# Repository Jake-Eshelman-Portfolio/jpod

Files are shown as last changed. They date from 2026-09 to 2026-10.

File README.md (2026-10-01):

# jPod Project Summary

## Goal
A handheld, music-only player about the size of an iPod Video. Stores 32–64GB of music, has a small screen with menus, a 4-way D-pad plus select, Bluetooth headphones, and a wired 3.5mm jack as backup.

## Core design
- **Brain:** ESP32-WROVER (original ESP32). It has classic Bluetooth for headphone audio, Wi-Fi, and 8MB of extra RAM for buffering.
- **Audio:** TI TLV320DAC3100 DAC with a built-in headphone amp, feeding a 3.5mm jack.
- **Storage:** microSD card.
- **Screen:** 2" ST7789 color display.
- **Power:** LiPo battery (1500–2500mAh), USB-C charging, battery-level chip.
- **Software:** Rust on ESP-IDF (`std`). Symphonia handles MP3/FLAC decoding and tags.

## Features
- **Local playback** from the SD card, browsing by artist and album.
- **Streaming** from Navidrome on the Pi over Wi-Fi. Away from home, it reaches the Pi through Tailscale Funnel, protected by a password and a secret token.
- **"Find similar":** pick a song, and the Pi asks Last.fm for similar tracks, then plays any matches from the library or adds the rest to a wishlist.
- **Firmware updates** over Wi-Fi.

## Decisions
- Start with one ESP32. Add a second one for Bluetooth only if streaming over Wi-Fi while playing through Bluetooth stutters.
- Use a 3.5mm jack instead of USB-C headphones.
- Leave LTE for v2, but reserve a spare UART and power header on v1.
- Skip Spotify's API, since it's too locked down now. Use Last.fm instead.

## Plan
1. **Prototype on a breadboard** with a dev kit and breakouts, powered over USB.
2. **Write the software:** playback, UI, Bluetooth, streaming, "find similar".
3. **Design the custom PCB in KiCad** using the same chips.
4. **Order parts.** Separate BOM for schematic based final build and the prototype that will be used to create a test bench.

## Prepare an SD Card (Linux/WSL)
1. Insert the card and inspect disks and partitions:
	```bash
	lsblk -o NAME,PATH,TRAN,RM,SIZE,MODEL,TYPE,FSTYPE,MOUNTPOINTS
	```
2. Identify the removable USB **disk** by model and capacity. Use the whole-disk path (for example, `/dev/sde`), not a partition path such as `/dev/sde1`. The script erases the whole selected disk and creates one MBR/FAT32 partition; Linux sees the USB reader and cannot prove what media is inserted.
3. Ensure `mp3_samples/` contains at least one MP3, then run from the repository root, substituting the verified disk path:
	```bash
	sudo ./helper_scripts/partition_sd_card.sh /dev/sde
	```
4. Check the script's printed model, capacity, and partition list carefully. Continue only if they match the SD card you intend to erase, then type the exact confirmation it requests (device path and size in bytes).

5. To check the music on card:
    - sudo mkdir -p /mnt/jpod-card
    - sudo mount /dev/sde1 /mnt/jpod-card
    - ls /mnt/jpod-card/mp3_samples
    - sudo umount /mnt/jpod-card

The script refuses mounted or otherwise in-use disks. Install its Linux tools if needed with `sudo apt install util-linux fdisk parted dosfstools udev coreutils findutils gawk` (`parted` provides `partprobe`).

## Watch out for
- Wi-Fi and Bluetooth share one radio on the ESP32, so buffer streams aggressively.
- The DAC needs its own 1.8V supply on the custom board.
- The CP2102N USB chip has a long lead time, so buy it early or find a good substitution.

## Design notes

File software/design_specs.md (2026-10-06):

# Software Design

## Main and Workers

- `main` initializes the hardware and starts the workers.
- Each worker owns its device state and runs on its own thread.
- Screen and SD workers are active objects, have mailbox and address that serves as interface

## Shared SPI Bus

- `main` owns one SPI bus driver.
- Screen and SD workers borrow the bus and create separate device handles with separate chip-select pins.
- ESP-IDF serializes transfers from these device handles on the shared bus.
- Lifetimes keep the device wrappers from outliving the bus

## Button Interrupts

- A normal thread runs `register_button_interrupts` and owns the button pins.
- A full screen mailbox drops that event. 
- A disconnected mailbox ends the button worker since program currently will restart if an active object fails

## Runtime and Failures

- Workers are intended to run for the whole powered session.
- Screen and SD threads use a scope because they borrow the SPI bus.
- The button thread uses normal `spawn` because it owns its inputs and does not borrow the bus.
- A worker exit or handled startup failure logs a short reason and restarts the chip.
- We do not join running workers for shutdown since we plan to full restart anyways
- TODO: Log detailed worker errors before restarting.

## Power and Sleep

- Add explicit worker shutdown later only if we need task restarts or tests that must end cleanly.

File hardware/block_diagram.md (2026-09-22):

```mermaid
flowchart TB
    USB["USB-C"] --> UART["USB-UART<br/>CP2102N"]
    USB --> PWR["Power<br/>Charger + 3.3V Regulator"]
    BATT["LiPo Battery"] --- PWR
    PWR -->|3.3V| MCU

    UART -->|UART| MCU
    MCU["ESP32-WROVER-E"]

    MCU -->|I2S / I2C| DAC["Audio DAC<br/>TLV320DAC3100"] --> JACK["3.5mm Jack"]
    MCU -->|SPI via 22-pin FFC| DISP["Display<br/>ER-TFT020-7"]
    MCU -->|SPI| SD["microSD"]
    BTN["Buttons / D-pad"] -->|GPIO| MCU
```

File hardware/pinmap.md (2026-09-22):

# ESP32-WROVER-E-N16R8 — Pin Map / Plan

DIY music player (JPod). Module: **ESP32-WROVER-E-N16R8** (16 MB flash, 8 MB PSRAM).

> **WROVER note:** GPIO6–11 are used internally for SPI flash and GPIO16/17 for PSRAM — none are broken out on this module, so they don't appear here. Don't plan to use them.

---

## 1. Peripheral assignment (the plan)

| Function | Signal | GPIO | Notes |
| --- | --- | --- | --- |
| **I²C** (DAC ctrl + fuel gauge) | SDA | IO21 | 4.7k pull-up to 3V3 |
| | SCL | IO22 | 4.7k pull-up to 3V3 |
| **I²S** (audio → TLV320DAC3100) | BCLK | IO26 | |
| | WS / LRCLK | IO25 | |
| | DOUT (data to DAC) | IO14 | |
| | MCLK | *(optional)* GPIO0 | DAC can run off BCLK via internal PLL; only wire MCLK if needed — GPIO0 is shared with boot/auto-reset, so avoid if you can |
| **SPI bus** (ER-TFT020-7 display + SD, shared) | SCK | IO18 | |
| | MOSI | IO23 | |
| | MISO | IO19 | SD only (ST7789 is write-only) |
| **Display (ER-TFT020-7)** | CS | IO5 | strapping — safe as an output |
| | DC | IO27 | |
| | RST | *(tie to EN)* | share the ESP32 reset to save a pin, or use a free GPIO |
| | BL (backlight) | IO4 | PWM dimming |
| **microSD (DM3AT)** | CS | IO13 | |
| **Buttons — D-pad** | Up | IO34 | input-only → **needs external 10k pull-up** |
| | Down | IO35 | input-only → **external 10k pull-up** |
| | Left | IO36 (SENSOR_VP) | input-only → **external 10k pull-up** |
| | Right | IO39 (SENSOR_VN) | input-only → **external 10k pull-up** |
| **Button — Select** | SEL | IO32 | internal pull-up OK |
| **HP jack detect** | DET | IO33 | optional; confirm detect contact on SJ-43514 |
| **Fuel gauge ALRT** | ALRT | *(optional)* IO15 | idles high (OK at boot); or leave NC and poll over I²C |
| **Charger status** | CHG / PGOOD | *(optional)* NC | BQ24075 open-drain status; wire only if pins free |

**Reserved — do not reassign:**

| Signal | GPIO / Pin | Why |
| --- | --- | --- |
| EN | pin 3 | reset/enable — pull-up + RC cap |
| IO0 | pin 25 | boot strap + auto-reset circuit |
| TXD0 | GPIO1 (pin 35) | UART0 — programming/serial console |
| RXD0 | GPIO3 (pin 34) | UART0 — programming/serial console |

---

## 2. Full pin reference (all 47)

| Pin | Label | GPIO | Class | Plan |
| --- | --- | --- | --- | --- |
| 1 | GND_2 | — | power | GND |
| 2 | 3V3 | — | power | 3.3V rail |
| 3 | EN | — | reset | pull-up + RC; opt. LCD_RST here |
| 4 | SENSOR_VP | IO36 | **input-only** | Btn Left (ext pull-up) |
| 5 | SENSOR_VN | IO39 | **input-only** | Btn Right (ext pull-up) |
| 6 | IO34 | IO34 | **input-only** | Btn Up (ext pull-up) |
| 7 | IO35 | IO35 | **input-only** | Btn Down (ext pull-up) |
| 8 | IO32 | IO32 | full GPIO | Btn Select |
| 9 | IO33 | IO33 | full GPIO | HP jack detect |
| 10 | IO25 | IO25 | full GPIO (DAC) | I²S WS |
| 11 | IO26 | IO26 | full GPIO (DAC) | I²S BCLK |
| 12 | IO27 | IO27 | full GPIO | LCD DC |
| 13 | IO14 | IO14 | full GPIO | I²S DOUT |
| 14 | IO12 | IO12 | **strap (boot LOW)** | free — keep low/floating at boot |
| 15 | GND_3 | — | power | GND |
| 16 | IO13 | IO13 | full GPIO | SD CS |
| 17–22 | NC_2–7 | — | n/c | leave open |
| 23 | IO15 | IO15 | **strap (idles high)** | opt. fuel-gauge ALRT |
| 24 | IO2 | IO2 | **strap (boot LOW/float)** | free — use carefully |
| 25 | IO0 | IO0 | **strap / boot** | boot + auto-reset (reserved) |
| 26 | IO4 | IO4 | full GPIO | LCD backlight (PWM) |
| 27 | NC_8 | — | n/c | leave open |
| 28 | NC_9 | — | n/c | leave open |
| 29 | IO5 | IO5 | strap (safe as output) | LCD CS |
| 30 | IO18 | IO18 | full GPIO | SPI SCK |
| 31 | IO19 | IO19 | full GPIO | SPI MISO |
| 32 | NC | — | n/c | leave open |
| 33 | IO21 | IO21 | full GPIO | I²C SDA |
| 34 | RXD0 | IO3 | UART0 | serial console (reserved) |
| 35 | TXD0 | IO1 | UART0 | serial console (reserved) |
| 36 | IO22 | IO22 | full GPIO | I²C SCL |
| 37 | IO23 | IO23 | full GPIO | SPI MOSI |
| 38 | GND | — | power | GND |
| 39–47 | EPAD / EPAD_2–9 | — | thermal pad | all to GND |

---

## 3. Constraints cheat-sheet

- **Input-only (no output, no internal pull-up):** GPIO34, 35, 36, 39 → used for the 4 D-pad buttons, each with an **external 10k pull-up** to 3V3, button to GND.
- **Strapping pins** (level at power-up sets boot behavior): IO0, IO2, IO5, IO12, IO15.
  - IO12 must be **LOW at boot** (sets flash voltage) — don't hang a pulled-high signal on it.
  - IO0 → boot/download select, owned by auto-reset circuit.
  - IO5 / IO15 default high — fine as outputs / high-idle inputs.
- **UART0 (IO1/IO3):** keep for CP2102N programming + console.
- Add **test pads / header** for TXD0, RXD0, EN, IO0, GND — manual-flash fallback if the auto-reset circuit has a bug on rev A.

---

## 4. Firmware defines (Arduino / ESP-IDF)

```c
// ---- I2C ----
#define PIN_I2C_SDA    21
#define PIN_I2C_SCL    22

// ---- I2S (audio to TLV320DAC3100) ----
#define PIN_I2S_BCLK   26
#define PIN_I2S_WS     25
#define PIN_I2S_DOUT   14
// #define PIN_I2S_MCLK 0   // only if DAC PLL not used

// ---- SPI (display + SD) ----
#define PIN_SPI_SCK    18
#define PIN_SPI_MOSI   23
#define PIN_SPI_MISO   19
#define PIN_LCD_CS     5
#define PIN_LCD_DC     27
#define PIN_LCD_BL     4
// LCD_RST tied to EN
#define PIN_SD_CS      13

// ---- Buttons ----
#define PIN_BTN_UP     34   // input-only, ext pull-up
#define PIN_BTN_DOWN   35   // input-only, ext pull-up
#define PIN_BTN_LEFT   36   // input-only, ext pull-up
#define PIN_BTN_RIGHT  39   // input-only, ext pull-up
#define PIN_BTN_SEL    32   // internal pull-up

// ---- Misc ----
#define PIN_HP_DETECT  33
// #define PIN_FUELGAUGE_ALRT 15  // optional
```

---

## 5. Open items

- [ ] Confirm SJ-43514 detect-pin behavior (which contact, active level).
- [ ] Decide MCLK: rely on DAC internal PLL (preferred) vs wire GPIO0.
- [ ] Verify the ER-TFT020-7 FFC pinout, power rails, and backlight connection before finalizing the display net labels.
- [ ] Confirm FH12-22S-0.5SH(55) footprint, FFC contact orientation, and cable length.
- [ ] Decide LCD_RST: tie to EN vs dedicate a GPIO.
- [ ] Wire BQ24075 CHG/PGOOD status to GPIO? (optional UI nicety)
- [ ] Add external 10k pull-ups for the 4 input-only D-pad buttons.

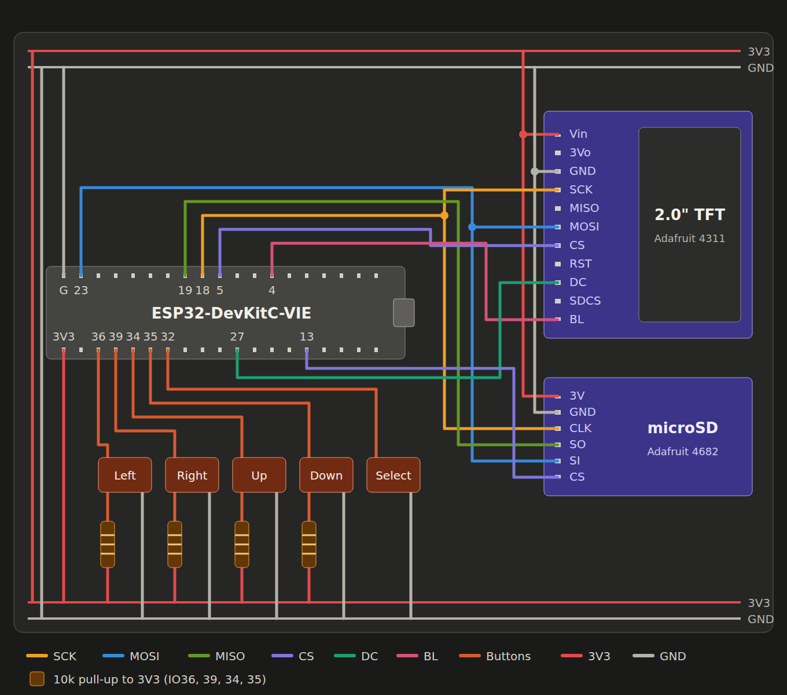
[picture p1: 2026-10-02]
hardware/jpod_breadboard.png

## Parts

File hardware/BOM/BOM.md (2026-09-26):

# JPod BOM Selection Record

## Availability Basis

`bom_prototype.csv` and `bom_schematic.csv` were checked with the DigiKey Product Information API on 2026-09-19. An item described as **in stock** below is Active with a positive quantity returned by that API. The API returned no on-hand quantity for a few active listings; those are marked **cart check required** and must not be released to purchase until their cart quantity is confirmed. This avoids treating an Active listing as proof of stock.

The prototype and first hardware build share the ESP32-WROVER platform, TLV320DAC3100 audio family, and microSD approach. The prototype uses the Adafruit 4311 display breakout, while the final hardware build uses the ER-TFT020-7 display through its dedicated FFC connector.

## Prototype Test Bench

| Part | DigiKey part | Selection and role |
| --- | --- | --- |
| ESP32-DEVKITC-VIE | `1965-ESP32-DEVKITC-VIE-ND` | This stocked ESP32-WROVER-IE development board preserves the original ESP32 classic Bluetooth and WROVER PSRAM for prototype firmware and uses the separate IPEX antenna below. |
| ANTX200P001B24003 | `311-1553-ND` | This stocked 2.4 GHz flat-patch IPEX antenna connects to the VIE board for prototype Wi-Fi and Bluetooth, and should be kept away from metal and the battery. |
| Adafruit 6309 | `1528-6309-ND` | This stocked TLV320DAC3100 breakout converts I2S audio to headphone-level analog output and lets the bench use the same audio codec family as the hardware build. |
| Adafruit 4682 | `1528-4682-ND` | This stocked microSD breakout holds the music library and exposes the card interface to the ESP32. |
| Adafruit 4311 | `1528-4311-ND` | This stocked 2-inch ST7789 display module provides the player UI for the prototype bench. |
| Adafruit 1119 | `1528-1119-ND` | This stocked tactile-button pack provides the five switches needed for the D-pad and select input. |
| Adafruit 239 | `1528-239-ND` | This stocked full-size breadboard provides the reusable wiring surface for the bench setup; it replaces the previous camera-cable part number. |
| WK-3 | `BKWK-3-ND` | This stocked 70-piece 22 AWG jumper kit connects the breakouts during bench work and replaces the unavailable Adafruit wire pack. |

## Hardware Build

| Part | DigiKey part | Selection and role |
| --- | --- | --- |
| ESP32-WROVER-E-N16R8 | `1965-ESP32-WROVER-E-N16R8CT-ND` | This stocked ESP32 module provides 16 MB flash and 8 MB PSRAM for the production compute, Wi-Fi, Bluetooth, and buffered-audio platform and has its own PCB antenna. |
| TLV320DAC3100IRHBT | `296-39266-1-ND` | This stocked TLV320DAC3100 in the same VQFN-32 package as the prototype codec converts I2S audio to headphone-level analog output. |
| TLV75518PDBVR | `296-50410-1-ND` | This stocked 1.8 V regulator powers the DAC digital supply within its required voltage range. |
| BQ24075RGTR | `296-38874-1-ND` | This stocked charger safely charges the single-cell LiPo while powering the player from USB. |
| APT1608SGC | `N/A` | Green 1608 SMD charge-indicator LED; verify supply, footprint, LED polarity, current-limiting resistor, and charger status wiring before release. |
| APT1608SYCK | `N/A` | Yellow 1608 SMD charge-indicator LED; verify supply, footprint, LED polarity, current-limiting resistor, and charger status wiring before release. |
| TPS63020DSJT | `296-27230-1-ND` | This stocked buck-boost regulator holds the system rail at 3.3 V as the battery voltage rises and falls. |
| SRP4020TA-1R5M | `SRP4020TA-1R5MCT-ND` | Stocked Bourns shielded 1.5 uH +/-20% inductor for the TPS63020; 7 A saturation, 4.5 A rated current, 42 milliohm max DCR. Its 4.45 x 4.06 x 2.00 mm body requires the Bourns land pattern for L1, not an assumed 4.0 x 4.0 mm footprint. Verify current and enclosure clearance before layout. [DigiKey product page](https://www.digikey.com/en/products/detail/bourns-inc/SRP4020TA-1R5M/4901003). |
| MAX17048G+T10 | `MAX17048G+T10CT-ND` | This stocked optional fuel-gauge IC reports battery state of charge to the firmware over I2C. |
| CP2102N-A02-GQFN24R | `336-5888-1-ND` | This stocked USB-to-UART bridge provides programming and serial debug, though its 31-week manufacturer lead time makes it a buy-early item. |
| MMBT3904-7-F | `MMBT3904-FDICT-ND` | These stocked SOT-23 NPN transistors implement ESP32 automatic reset and boot-mode control; verify pin mapping in the schematic. |
| USB4105-GF-A | `2073-USB4105-GF-ACT-ND` | This stocked USB-C receptacle brings in USB power and data. |
| RC0402FR-075K1L | `311-5.10KLRCT-ND` | These stocked 5.1 kOhm resistors advertise the device as a USB-C power sink on CC1 and CC2. |
| USBLC6-2P6 | `497-5026-1-ND` | This stocked USB ESD protector shields the USB data lines from static discharge, but its SOT-666 footprint and pinout must replace the former SOT-23-6 design. |
| DM3AT-SF-PEJM5 | `HR1964CT-ND` | This stocked push-push socket holds the removable microSD music card. |
| SJ-43514-SMT-TR | `CP-43514SJCT-ND` | This stocked 3.5 mm jack provides wired headphone audio and a detect contact; confirm the detect pin in the schematic. |
| TL3342F160QG/TR | `EG2531CT-ND` | These stocked low-profile switches form the D-pad and select button. |
| JS102011SAQN | `401-1999-1-ND` | This stocked SPDT switch is used for power or hold control. |
| S2B-PH-SM4-TB | `455-S2B-PH-SM4-TBCT-ND` | This stocked JST-PH connector mates the protected LiPo battery to the board. |
| Adafruit 328 | `1528-1840-ND` | This stocked 3.7 V 2500 mAh LiPo pouch cell has a built-in protection circuit and a JST PHR-2 lead that mates with `S2B-PH-SM4-TB`. Adafruit wires red (+) to pin 1, so the connector must be BAT+ on pin 1 and GND on pin 2; check this against the cell drawing. Use Adafruit 2011 (`1528-1857-ND`, 2000 mAh) as the alternate if the enclosure is too tight. |
| ER-TFT020-7 | `N/A` | Final 2-inch TFT display for the custom board. Confirm the controller pinout, power rails, mechanical fit, and compatible 22-position 0.5 mm FFC cable before release. |
| FH12-22S-0.5SH(55) | `H125180CT-ND` | Hirose 22-position, 0.5 mm pitch FFC/FPC PCB header for the ER-TFT020-7. Confirm FFC contact orientation and cable length; [DigiKey product page](https://www.digikey.com/en/products/detail/hirose-electric-co-ltd/FH12-22S-0-5SH-55/1110380). |
| Passives | `N/A` | Decoupling capacitors, pull-ups, and regulator/charger-setting resistors are a **hold** until the schematic specifies their values, quantities, voltage ratings, and footprints. |

## Obsolete Part Note

- `TPS65810RTQT` is considered obsolete for this project and should not be added to future BOM revisions.
- If that PMIC family is required for a derivative design, prefer `TPS65810RTQR` first, with `TPS65811RTQR` as a secondary option.
- Before release, perform rail-by-rail output verification, I2C register-map comparison, startup-sequence validation, and charger behavior checks.

## Purchase Release Checklist

1. Order the listed IPEX antenna with the ESP32-DEVKITC-VIE and keep it clear of metal and the battery during bench testing.
2. Fit-check the Adafruit 328 pouch cell (or 2011 alternate) against the enclosure. Before PCB release, add the `S2B-PH-SM4-TB` battery connector to the schematic with pin 1 = BAT+ and pin 2 = GND, and confirm this matches the cell's lead drawing.
3. Finish the schematic, add both charge-indicator LEDs with suitable current-limiting resistors and validated charger status wiring, and replace the passive placeholder with individual, stocked component lines.
4. For the custom PCB, keep the WROVER-E module's PCB antenna at the board edge and follow Espressif's antenna keepout; do not add a chip antenna or external antenna unless switching to an external-antenna ESP32 module.
5. Confirm the TPS63020 inductor current and thermal limits, transistor pinout, USB ESD SOT-666 footprint and pinout, jack-detect wiring, and ER-TFT020-7 FFC pinout, cable orientation, and mechanical mounting before ordering the custom PCB.

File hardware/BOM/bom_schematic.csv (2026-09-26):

Quantity | Manufacturer Part Number | DigiKey Part Number | Description | Availability (checked 2026-09-19) | Notes | Found MPN | DK Part # (small qty) | Status | Qty Available | Unit Price | Mfr Lead (wks) | URL
1 | ESP32-WROVER-E-N16R8 | 1965-ESP32-WROVER-E-N16R8CT-ND | ESP32 module 16MB flash / 8MB PSRAM PCB antenna | Active; 15199 in stock (2026-09-20) | Requested schematic module; qty 2 if dual-ESP32 BT offload | ESP32-WROVER-E-N16R8 | 1965-ESP32-WROVER-E-N16R8CT-ND | Active | 15199 | 6.32 | 8 | https://www.digikey.com/en/products/detail/espressif-systems/ESP32-WROVER-E-N16R8/11613135
1 | TLV320DAC3100IRHBT | 296-39266-1-ND | Stereo audio DAC with headphone amp VQFN-32 | Active; 120 in stock (2026-09-19) | Same DAC and VQFN-32 package as prototype breakout; replaces out-of-stock TLV320DAC3100IRHBR packaging | TLV320DAC3100IRHBT | 296-39266-1-ND | Active | 120 | 2.34 | 16 | https://www.digikey.com/en/products/detail/texas-instruments/TLV320DAC3100IRHBT/2353656
1 | TLV75518PDBVR | 296-50410-1-ND | 1.8V 500mA LDO SOT-23-5 | Active; 16399 in stock (2026-09-19) | For DAC DVDD (1.65-1.95V) | TLV75518PDBVR | 296-50410-1-ND | Active | 16399 | 0.42 | 9 | https://www.digikey.com/en/products/detail/texas-instruments/TLV75518PDBVR/9356529
1 | BQ24075RGTR | 296-38874-1-ND | 1-cell Li-ion charger with power-path | Active; 3026 in stock (2026-09-19) |  | BQ24075RGTR | 296-38874-1-ND | Active | 3026 | 2.43 | 9 | https://www.digikey.com/en/products/detail/texas-instruments/BQ24075RGTR/2047273
1 | APT1608SGC | N/A | Green 1608 SMD LED for charge indication | HOLD: verify supplier availability and DigiKey part number | Add LED and current-limit resistor to charger indicator circuit; verify BQ24075 status-pin behavior and LED polarity before PCB release | APT1608SGC | N/A | UNVERIFIED
1 | APT1608SYCK | N/A | Yellow 1608 SMD LED for charge indication | HOLD: verify supplier availability and DigiKey part number | Add LED and current-limit resistor to charger indicator circuit; verify BQ24075 status-pin behavior and LED polarity before PCB release | APT1608SYCK | N/A | UNVERIFIED
1 | TPS63020DSJT | 296-27230-1-ND | 3.3V buck-boost regulator | Active; 1860 in stock (2026-09-19) | DSJT is the verified stocked package variant | TPS63020DSJT | 296-27230-1-ND | Active | 1860 | 5.0 | 16 | https://www.digikey.com/en/products/detail/texas-instruments/TPS63020DSJT/2263063
1 | SRP4020TA-1R5M | SRP4020TA-1R5MCT-ND | Shielded 1.5uH 20% power inductor for TPS63020 | Active; 18424 in stock (2026-09-25) | Bourns 4020 class: 4.45 x 4.06 x 2.00mm body; 7A saturation and 42mOhm max DCR; assign manufacturer land pattern to L1 and check peak/RMS current and enclosure before layout | SRP4020TA-1R5M | SRP4020TA-1R5MCT-ND | Active | 18424 | 1.07 |  | https://www.digikey.com/en/products/detail/bourns-inc/SRP4020TA-1R5M/4901003
1 | MAX17048G+T10 | MAX17048G+T10CT-ND | LiPo fuel gauge I2C | Active; 24932 in stock (2026-09-19) | Optional | MAX17048G+T10 | MAX17048G+T10CT-ND | Active | 24932 | 4.61 | 13 | https://www.digikey.com/en/products/detail/analog-devices-inc-maxim-integrated/MAX17048G-T10/3758921
1 | CP2102N-A02-GQFN24R | 336-5888-1-ND | USB-to-UART bridge QFN-24 | Active; 13500 in stock (2026-09-19) | 31-week manufacturer lead time; buy early | CP2102N-A02-GQFN24R | 336-5888-1-ND | Active | 13500 | 5.15 | 31 | https://www.digikey.com/en/products/detail/silicon-labs/CP2102N-A02-GQFN24R/9863479
2 | MMBT3904-7-F | MMBT3904-FDICT-ND | NPN transistor SOT-23 | Active; 60513 in stock (2026-09-19) | Replaces inventory-inconsistent MMBT3904LT1G for ESP32 auto-reset (EN/IO0); verify pinout against schematic | MMBT3904-7-F | MMBT3904-FDICT-ND | Active | 60513
1 | USB4105-GF-A | 2073-USB4105-GF-ACT-ND | USB-C receptacle 16-pin | Active; 131974 in stock (2026-09-19) |  | USB4105-GF-A | 2073-USB4105-GF-ACT-ND | Active | 131974 | 0.8 | 7 | https://www.digikey.com/en/products/detail/gct/USB4105-GF-A/11198441
2 | RC0402FR-075K1L | 311-5.10KLRCT-ND | 5.1k 0402 resistor | Active; 977798 in stock (2026-09-19) | USB-C CC1/CC2 pulldowns | RC0402FR-075K1L | 311-5.10KLRCT-ND | Active | 977798 | 0.1 | 17 | https://www.digikey.com/en/products/detail/yageo/RC0402FR-075K1L/726624
1 | USBLC6-2P6 | 497-5026-1-ND | USB ESD protection diode array | Active; 104049 in stock (2026-09-19) | Replaces out-of-stock USBLC6-2SC6; verify the SOT-666 footprint and pinout because it is not a SOT-23-6 drop-in | USBLC6-2P6 | 497-5026-1-ND | Active | 104049 | 0.26 | 14 | https://www.digikey.com/en/products/detail/stmicroelectronics/USBLC6-2P6/1007440
1 | DM3AT-SF-PEJM5 | HR1964CT-ND | MicroSD push-push socket | Active; 27897 in stock (2026-09-19) |  | DM3AT-SF-PEJM5 | HR1964CT-ND | Active | 27897 | 3.55 | 16 | https://www.digikey.com/en/products/detail/hirose-electric-co-ltd/DM3AT-SF-PEJM5/2533565
1 | SJ-43514-SMT-TR | CP-43514SJCT-ND | 3.5mm 4-pole SMT jack with detect switch | Active; 7051 in stock (2026-09-19) | Confirm detect pin in schematic | SJ-43514-SMT-TR | CP-43514SJCT-ND | Active | 7051 | 1.52 | 13 | https://www.digikey.com/en/products/detail/same-sky-formerly-cui-devices/SJ-43514-SMT-TR/669724
5 | TL3342F160QG/TR | EG2531CT-ND | Low-profile SMD tactile switch | Active; 75251 in stock (2026-09-19) | D-pad + select | TL3342F160QG/TR | EG2531CT-ND | Active | 75251 | 0.59 | 17 | https://www.digikey.com/en/products/detail/e-switch/TL3342F160QG-TR/379003
1 | JS102011SAQN | 401-1999-1-ND | SPDT slide switch | Active; 55924 in stock (2026-09-19) | Power/hold | JS102011SAQN | 401-1999-1-ND | Active | 55924 | 0.85 | 14 | https://www.digikey.com/en/products/detail/c-k/JS102011SAQN/1640095
1 | S2B-PH-SM4-TB | 455-S2B-PH-SM4-TBCT-ND | JST PH 2-pin SMD battery connector | Active; 157221 in stock (2026-09-19) | Match battery lead | S2B-PH-SM4-TB | 455-S2B-PH-SM4-TBCT-ND | Active | 157221 | 0.49 | 16 | https://www.digikey.com/en/products/detail/jst-sales-america-inc/S2B-PH-SM4-TB/926655
1 | 328 | 1528-1840-ND | Adafruit LiPo pouch cell 3.7V 2500mAh with protection circuit and JST PHR-2 lead | Active; 1320 in stock (2026-09-24) | JST PHR-2 housing mates S2B-PH-SM4-TB; Adafruit lead is red (+) on pin 1 - wire connector pin 1 = BAT+ and pin 2 = GND and verify against the cell drawing; alternate Adafruit 2011 (1528-1857-ND 2000mAh 51 in stock) if enclosure is tight | 328 | 1528-1840-ND | Active | 1320 | 14.95 |  | https://www.digikey.com/en/products/detail/adafruit-industries-llc/328/5054542
1 | ER-TFT020-7 | N/A | Final 2.0in TFT display module | HOLD: verify supplier availability before order | Final custom-board display; verify its controller pinout and power rails plus the compatible 22-position 0.5 mm FFC cable before PCB release | ER-TFT020-7 | N/A | UNVERIFIED
1 | FH12-22S-0.5SH(55) | H125180CT-ND | 22-position 0.5 mm pitch bottom-contact FFC/FPC connector | HOLD: recheck DigiKey stock before order | Mating PCB header for ER-TFT020-7; confirm FFC contact orientation and cable length against the display | FH12-22S-0.5SH(55) | H125180CT-ND | UNVERIFIED |  |  |  | https://www.digikey.com/en/products/detail/hirose-electric-co-ltd/FH12-22S-0-5SH-55/1110380
1 | Passives kit | N/A | Decoupling caps / pull-ups / charger & regulator resistors | HOLD: values and quantities are not yet in a schematic | Create line items from each IC reference design before releasing a purchase order |  |  | SKIPPED

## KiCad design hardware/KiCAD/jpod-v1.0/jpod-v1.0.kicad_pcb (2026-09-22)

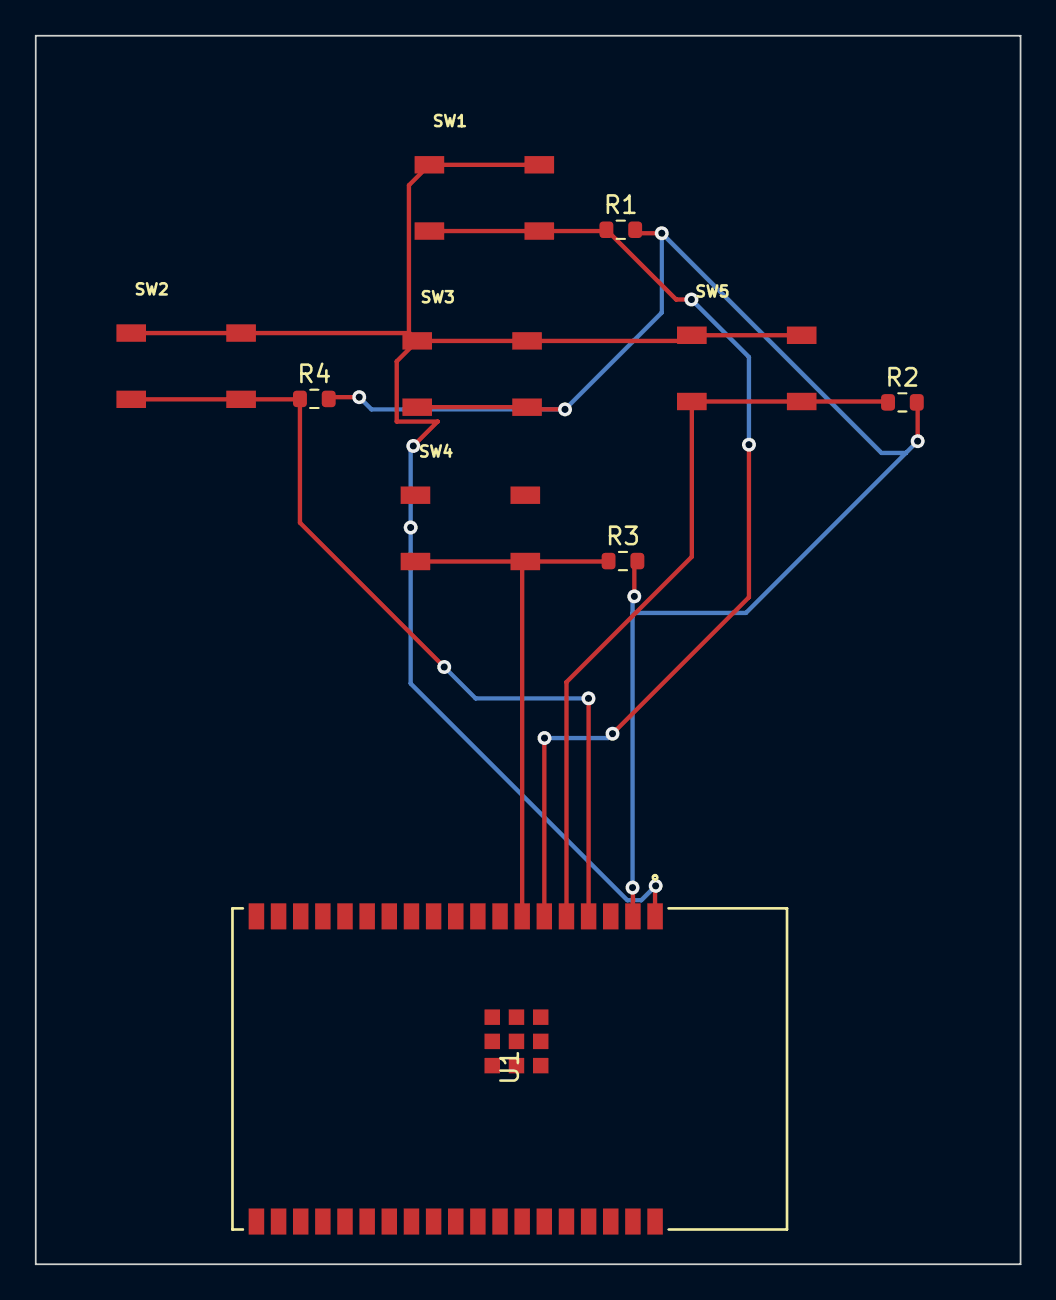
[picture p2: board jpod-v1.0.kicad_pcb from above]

Board: 2 copper layers, 56.5 x 70.4 mm, 10 parts (0 on the bottom side), 6 nets.

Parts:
R1, R2, R3, R4: 10K; R_0603_1608Metric
SW1, SW2, SW3, SW4, SW5: TL3342F160QG_TR; SW_TL3342F160QG_TR
U1: ESP32-WROVER-E-N16R8; ESP32-WROVER-E_EXP

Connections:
/3V3: R1.2, R2.2, R3.2, R4.2, SW3.1, SW3.2, U1.2 (3V3), U1.8 (IO32)
/GND: SW1.3, SW1.4, SW2.3, SW2.4, SW3.3, SW3.4, SW4.3, SW4.4, SW5.3, SW5.4, U1.1 (GND_2)
/btn_down: R3.1, SW4.1, SW4.2, U1.7 (IO35)
/btn_left: R4.1, SW2.1, SW2.2, U1.4 (SENSOR_VP)
/btn_right: R2.1, SW5.1, SW5.2, U1.5 (SENSOR_VN)
/btn_up: R1.1, SW1.1, SW1.2, U1.6 (IO34)

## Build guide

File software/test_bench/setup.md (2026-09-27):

# ESP32 build and flash setup (WSL2)

This project builds ESP-IDF firmware for the original Xtensa ESP32. The Cargo
configuration targets `xtensa-esp32-espidf`, uses ESP-IDF v5.5.3, links with
`ldproxy`, and runs firmware with `espflash flash --monitor`. Firmware cannot
run as a Linux executable: `cargo run` builds it, flashes an attached ESP32,
and opens its serial monitor.

## Rust and Cargo in WSL

On a fresh Ubuntu WSL installation, install the basic host tools first:

```bash
sudo apt update
sudo apt install -y curl ca-certificates git build-essential python3 python3-venv
```

Install Rust and Cargo through the official rustup installer (accept the
default stable toolchain when prompted):

```bash
curl --proto '=https' --tlsv1.2 -sSf https://sh.rustup.rs | sh
source "$HOME/.cargo/env"
rustc +stable --version
cargo +stable --version
```

Rustup adds Cargo to the PATH for future shells; sourcing `~/.cargo/env`
makes it available immediately in the current shell. The `+stable` commands
below explicitly use stable Rust even inside this project, which selects
the `esp` toolchain through `rust-toolchain.toml`.

## Tools installed in WSL

Rust and Cargo were already installed on this WSL instance, so the preceding
fresh-install commands were not run here. These commands were used to add the
missing ESP tools:

```bash
cargo +stable install espup --locked
espup install
cargo +stable install ldproxy --locked
cargo +stable install espflash --locked
```

`espup install` installs the `esp` Rust toolchain, the Xtensa cross-compiler,
and Clang tooling. It generates `~/export-esp.sh`, which sets the compiler
`PATH` and `LIBCLANG_PATH`. Source it in each new WSL shell before building:

```bash
source "$HOME/export-esp.sh"
```

`ldproxy` is the linker named in `.cargo/config.toml`; without it, the build
fails with `linker 'ldproxy' not found`. `espflash` is the configured Cargo
runner; without it, `cargo run` builds but cannot launch the flash command.
ESP-IDF and its build tools are fetched by the project build as needed. No
system package installation was needed for the successful build here.

## Build

From this project directory in WSL:

```bash
source "$HOME/export-esp.sh"
cargo clean  # optional: removes previous build artifacts
cargo build
```

The clean and build completed successfully after installing the tools above.
The first build can take a while as it downloads and compiles ESP-IDF. You do
not need a connected ESP32 to run `cargo build`.

## Attach the board and flash

Connect the board to Windows, then in **Windows PowerShell**:

```powershell
usbipd list
usbipd bind --busid <BUSID>       # run as Administrator; normally once per device
usbipd attach --wsl --busid <BUSID>
```

Replace `<BUSID>` with the board's bus ID from `usbipd list`. In **WSL**:

```bash
ls /dev/ttyUSB* /dev/ttyACM* 2>/dev/null
source "$HOME/export-esp.sh"
cargo run
```

Linux has the `cp210x`, `ch341`, and `cdc_acm` kernel modules available for
common ESP32 USB connections; no separate Linux USB-serial driver was installed.
A Windows CP210x driver is not required solely for USB passthrough, though it
may be useful to access the board as a Windows COM port. If the WSL serial port
exists but access is denied, add your user to `dialout` and start a new WSL
session:

```bash
sudo usermod -aG dialout "$USER"
```

`cargo run` was tested without the board connected: the firmware built, then
`espflash` reported `No serial ports could be detected`. Flashing and the
`Hello, world!` log message still need verification with an attached board.

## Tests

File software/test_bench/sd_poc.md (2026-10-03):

# SD SPI Bring-up

Extracted from `poc_dac_ble_wifi_data` onto `main`, without DAC, BLE, or Wi-Fi changes.

The SD card shares SPI2 with the display: SCK GPIO18, MOSI GPIO23,
MISO GPIO19, SD CS GPIO13, and LCD CS GPIO5. The shared SPI driver uses
DMA for transfers larger than the non-DMA limit, including 512-byte sectors.
SD initialization runs before display initialization.

Use a FAT16/FAT32 card. Long filenames are enabled with
`CONFIG_FATFS_LFN_HEAP=y`. Build with `cargo build` from this directory;
`cargo run` flashes the attached ESP32 and opens its serial monitor.

`sd::init` mounts the card at `/sdcard`, creates or overwrites
`/sdcard/JPODTEST.TXT`, verifies its contents, then deletes the test file.
It returns the mount guard so the filesystem stays mounted. `main` calls the
public `sd::list_files_recursive("/sdcard")` to log files in all directories.
Expected log: `sd: write + read-back + delete OK`. SD errors are logged and
the display still starts. The mount is released when the guard is dropped.

The repository's SD preparation helper copies samples into `/mp3_samples`
on the card; their mounted firmware path would be `/sdcard/mp3_samples`.
This diagnostic does not yet browse that folder, decode MP3s, or play audio.
It does not format the card. File reads/writes still need validation on hardware.

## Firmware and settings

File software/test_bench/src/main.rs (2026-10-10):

pub mod active_object;
mod buttons;
pub mod pins;
mod screen;
pub(crate) mod sd;
mod shared_types;

use esp_idf_svc::hal::delay::FreeRtos;
use esp_idf_svc::hal::{
    gpio::{Gpio13, Gpio27, Gpio4, Gpio5, Gpio18, Gpio19, Gpio23},
    peripherals::Peripherals,
    spi::{SpiDriver, SPI2, Dma, SpiDriverConfig},
};
use std::{
    num::NonZeroUsize,
    thread::{self, Scope},
};

use esp_idf_svc::sys::EspError;

use active_object::Address;
use screen::ScreenMessage;

fn init_esp32() {
    // It is necessary to call this function once. Otherwise, some patches to the runtime
    // implemented by esp-idf-sys might not link properly. See https://github.com/esp-rs/esp-idf-template/issues/71
    esp_idf_svc::sys::link_patches();

    // Bind the log crate to the ESP Logging facilities
    esp_idf_svc::log::EspLogger::initialize_default();
}

fn init_peripherals() -> (SPI2<'static>, pins::BoardPins) {
    let peripherals = Peripherals::take().unwrap();
    let pins = pins::board_pins(peripherals.pins);
    (peripherals.spi2, pins)
}

pub fn new_spi_bus(
    spi: SPI2<'static>,
    sck: Gpio18<'static>,
    mosi: Gpio23<'static>,
    miso: Gpio19<'static>,
) -> Result<SpiDriver<'static>, EspError> {
    SpiDriver::new(
        spi,
        sck,
        mosi,
        Some(miso),
        &SpiDriverConfig::new().dma(Dma::Auto(4096)),
    )
}

fn start_screen_worker<'scope, 'env: 'scope>(
    scope: &'scope Scope<'scope, 'env>,
    bus: &'env SpiDriver<'env>,
    cs: Gpio5<'env>,
    dc: Gpio27<'env>,
    bl: Gpio4<'env>,
) -> (Address<ScreenMessage>, screen::ScreenWorker<'scope>) {
    let (address, mailbox) = active_object::mailbox(NonZeroUsize::new(8).unwrap());
    let worker = screen::spawn_screen_worker(scope, mailbox, bus, cs, dc, bl);
    (address, worker)
}

fn start_sd_worker<'scope, 'env: 'scope>(
    scope: &'scope Scope<'scope, 'env>,
    bus: &'env SpiDriver<'env>,
    cs: Gpio13<'env>,
) -> (Address<sd::SdMessage>, sd::SdWorker<'scope>) {
    let (address, mailbox) = active_object::mailbox(NonZeroUsize::new(8).unwrap());
    let worker = sd::spawn_sd_worker(scope, mailbox, bus, cs);
    (address, worker)
}

fn restart_on_failure(reason: &str) -> ! {
    // TODO: Log detailed worker errors before restarting.
    log::error!("{reason}; restarting");
    esp_idf_svc::hal::reset::restart()
}

fn main() {
    init_esp32();
    let (spi2, pins) = init_peripherals();

    let bus = new_spi_bus(spi2, pins.spi_sck, pins.spi_mosi, pins.spi_miso)
        .unwrap_or_else(|_| restart_on_failure("SPI bus setup failed"));

    let buttons = buttons::init_buttons(
        pins.btn_up,
        pins.btn_down,
        pins.btn_left,
        pins.btn_right,
        pins.btn_sel,
    )
    .unwrap_or_else(|_| restart_on_failure("Button setup failed"));


    // Scope provides a boundary for each active object's thread
    thread::scope(|scope| {
        let (screen_address, screen_worker) =
            start_screen_worker(scope, &bus, pins.lcd_cs, pins.lcd_dc, pins.lcd_bl);
        let (sd_address, sd_worker) = start_sd_worker(scope, &bus, pins.sd_cs);
        let button_worker = {
            let address = screen_address.clone();
            thread::Builder::new()
                .name("buttons".into())
                .spawn(move || {
                    buttons::register_button_interrupts(buttons, address)
                })
                .unwrap_or_else(|_| restart_on_failure("Failed to start button worker"))
        };

        if sd_address
            .post(sd::SdMessage::FetchSongs(screen_address.clone()))
            .is_err()
        {
            restart_on_failure("SD worker disconnected");
        }
        loop {
            FreeRtos::delay_ms(200);
            if screen_worker.is_finished() {
                restart_on_failure("Screen worker exited");
            }
            if sd_worker.is_finished() {
                restart_on_failure("SD worker exited");
            }
            if button_worker.is_finished() {
                restart_on_failure("Button worker exited");
            }
        }
    });
}

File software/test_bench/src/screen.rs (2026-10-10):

use std::{
    num::NonZeroUsize,
    ops::ControlFlow,
    thread::{Scope, ScopedJoinHandle},
    sync::Arc,
};

use crate::active_object::{ActiveObject, Mailbox};
use crate::shared_types::Song;
use display_interface_spi::SPIInterfaceNoCS;
use embedded_graphics::{
    mono_font::{ascii::FONT_10X20, MonoTextStyle},
    pixelcolor::Rgb565,
    prelude::*,
    primitives::{Line, PrimitiveStyle, Rectangle},
    text::Text,
};
use embedded_hal::spi::MODE_3;
use esp_idf_svc::{
    hal::{
        delay::Ets, gpio::{Gpio4, Gpio5, Gpio27, Output, PinDriver}, spi::{SpiConfig, SpiDeviceDriver, SpiDriver}, units::FromValueType,
    }, sys::EspError,
};
use mipidsi::{models::ST7789, Builder, Display};

type St7789Display<'spi> = Display<
    SPIInterfaceNoCS<SpiDeviceDriver<'spi, &'spi SpiDriver<'spi>>, PinDriver<'spi, Output>>,
    ST7789,
    PinDriver<'spi, Output>,
>;

pub type ScreenWorker<'scope> = ScopedJoinHandle<'scope, Result<(), EspError>>;

// The display borrows the SPI bus, so the screen cannot outlive that bus.
struct Screen<'spi> {
    display: St7789Display<'spi>,
    backlight: PinDriver<'spi, Output>,
    width: u32,
    height: u32,
    last_status: Option<ScreenStatus>,
    current_position: usize,
    current_text: String,
    songs_reference: Arc<Vec<Song>>,
}

#[derive(Debug)]
pub enum ScreenMessage {
    ShareSongs(Arc<Vec<Song>>),
    SetStatus(ScreenStatus),
    ShortSelectPress(bool),
    DownPressed,
    UpPressed,
}

#[derive(Clone, Copy, Debug, PartialEq, Eq)]
pub enum ScreenStatus {
    UpPressed,
    DownPressed,
    LeftPressed,
    RightPressed,
    ShortPress,
}

// '_ is shorthand for matching lifetime of screen
impl Screen<'_> {
    const LINE_SPACING: u32 = FONT_10X20.character_size.height;
    const BOTTOM_CUTOFF: u32 = 40;
    const STATUS_SEPARATOR_THICKNESS: u32 = 5;
    const STATUS_CLEAR_HEIGHT: u32 = Self::BOTTOM_CUTOFF - Self::STATUS_SEPARATOR_THICKNESS;
    const STATUS_BASELINE_OFFSET: i32 = 10;
    // (self.height - bottom_cutoff - separator thickness) / line_spacing
    const MAX_SONGS_PER_SCREEN: usize = 13;

    fn clear_black(&mut self) {
        let bounds = Rectangle::new(Point::zero(), Size::new(self.width, self.height));
        bounds
            .into_styled(PrimitiveStyle::with_fill(Rgb565::BLACK))
            .draw(&mut self.display)
            .expect("ST7789 background draw failed");
    }
    
    fn clear_dimensions(&mut self, x: i32, y: i32, size_x: u32, size_y: u32) {
        let starting_point = Point::new(x, y);
        let rectangle_size = Size::new(size_x, size_y);
        let bounds = Rectangle::new(
            starting_point,
            rectangle_size,
        );
        bounds
            .into_styled(PrimitiveStyle::with_fill(Rgb565::BLACK))
            .draw(&mut self.display)
            .expect("ST7789 status clear failed");
    }

    fn draw_line(&mut self, y: i32) {
        Line::new(Point::new(0, y), Point::new(self.width as i32 - 1, y))
            .into_styled(PrimitiveStyle::with_stroke(
                Rgb565::WHITE,
                Self::STATUS_SEPARATOR_THICKNESS,
            ))
            .draw(&mut self.display)
            .expect("ST7789 line draw failed");
    }

    fn draw_status(&mut self, status: ScreenStatus) {
        let style = MonoTextStyle::new(&FONT_10X20, Rgb565::WHITE);
        self.clear_dimensions(0, (self.height - Screen::STATUS_CLEAR_HEIGHT) as i32, self.width, Screen::STATUS_CLEAR_HEIGHT);
        Text::new(
            unpack_screen_status(status),
            Point::new(0, self.height as i32 - Self::STATUS_BASELINE_OFFSET),
            style,
        )
        .draw(&mut self.display)
        .expect("ST7789 text draw failed");
    }

    fn set_highlight(&mut self) {
        self.draw_highlight(Rgb565::WHITE, Rgb565::BLACK);
    }

    fn draw_highlight(&mut self, background: Rgb565, foreground: Rgb565) {
        let visible_position = self.current_position % Self::MAX_SONGS_PER_SCREEN;
        let style = MonoTextStyle::new(&FONT_10X20, foreground);
        let text = Text::new(
            self.current_text.as_str(),
            Point::new(0, Self::LINE_SPACING as i32 * (visible_position as i32 + 1)),
            style,
        );
        let text_bounds = text.bounding_box();
        let bounds = Rectangle::new(
            Point::new(0, text_bounds.top_left.y),
            Size::new(self.width, text_bounds.size.height),
        );
        bounds
            .into_styled(PrimitiveStyle::with_fill(background))
            .draw(&mut self.display)
            .expect("ST7789 highlight background draw failed");
        text
        .draw(&mut self.display)
            .expect("ST7789 highlight text draw failed");
    }

    // Call this before we update the position to reset highlight to black
    fn clear_highlight(&mut self) {
        self.draw_highlight(Rgb565::BLACK, Rgb565::WHITE);
    }

    fn update_menu_position(&mut self, direction: ScreenStatus) {
        if direction == ScreenStatus::DownPressed {
            self.current_position = self.current_position
                .saturating_add(1)
                .min(self.songs_reference.len().saturating_sub(1));
        } else if direction == ScreenStatus::UpPressed {
            self.current_position = self.current_position.saturating_sub(1);
        }

        let max_name_chars = (self.width / FONT_10X20.character_size.width) as usize;
        self.current_text = self
            .songs_reference
            .get(self.current_position)
            .map(|song| song.name.chars().take(max_name_chars).collect())
            .unwrap_or_default();
    }

    fn draw_current_page(&mut self)
    {
        let style = MonoTextStyle::new(&FONT_10X20, Rgb565::WHITE);
        let song_area_height = self
            .height
            .saturating_sub(Self::BOTTOM_CUTOFF + Self::STATUS_SEPARATOR_THICKNESS);

        // Max length that can fit across the screen
        let max_name_chars = (self.width / FONT_10X20.character_size.width) as usize;
        let songs_per_screen = Self::MAX_SONGS_PER_SCREEN;
        let songs = Arc::clone(&self.songs_reference);

        let start = (self.current_position / songs_per_screen) * songs_per_screen;

        let end = start
            .saturating_add(songs_per_screen)
            .min(songs.len());

        // Start one letter height away from top to avoid rendering offscreen
        let mut baseline_y = Self::LINE_SPACING;

        Rectangle::new(Point::zero(), Size::new(self.width, song_area_height))
            .into_styled(PrimitiveStyle::with_fill(Rgb565::BLACK))
            .draw(&mut self.display)
            .expect("ST7789 song list clear failed");


        for song in &songs[start..end] {
            let display_name: String = song.name.chars().take(max_name_chars).collect();
            Text::new(&display_name, Point::new(0, baseline_y as i32), style)
                .draw(&mut self.display)
                .expect("ST7789 text draw failed");
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

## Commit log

2026-09-20 add digikey api helper scripts, update gitignore, update .env, add first pass bom
    [bom_prototype.csv, bom_schematic.csv]
2026-09-20 first pass on stock checks in py script and first bom
    [bom_prototype.csv, bom_schematic.csv]
2026-09-20 update BOM for hardware chip selection
    [bom_schematic.csv]
2026-09-20 kicad work and block_diagram for hardware
    [jpod-v1.0.kicad_pcb, jpod-v1.0.kicad_sch]
2026-09-21 kicad pcb v0
2026-09-21 kicad files
    [jpod-v1.0.kicad_sch]
2026-09-21 pin map
2026-09-21 update kicad lib
2026-09-21 ignore kicad autosave files
2026-09-22 dm3at sd card holder added to library. Schematic updated to add decoupling caps and SPI bus for SD card holder
    [jpod-v1.0.kicad_pcb, jpod-v1.0.kicad_sch]
2026-09-22 update display to use actual display screen in schematic
    [bom_schematic.csv]
2026-09-22 work on display
    [jpod-v1.0.kicad_sch]
2026-09-22 completed lcd header
    [jpod-v1.0.kicad_sch]
2026-09-22 schematic cleanup and notes
    [jpod-v1.0.kicad_sch]
2026-09-23 sch finished with DAC and 3.5mm jack
    [jpod-v1.0.kicad_sch]
2026-09-23 schematic warning cleanup. usb-C and lipo battery still left todo
    [jpod-v1.0.kicad_sch]
2026-09-24 add lipo charger, buck boost, fuel gauge, updated hardware parts
    [jpod-v1.0.kicad_sch]
2026-09-24 battery updates and switch added to library:
    [bom_schematic.csv, jpod-v1.0.kicad_sch]
2026-09-25 schematic work for charger completed
    [bom_schematic.csv, jpod-v1.0.kicad_sch]
2026-09-26 power sch finished
    [bom_schematic.csv, jpod-v1.0.kicad_sch]
2026-09-27 Hello world, cargo run, usbipd scripts all working on esp32
2026-10-01 SPI bus working for LCD screen. Displaying arbitrary array of text to be replaced with song data.
    [main.rs, pins.rs, screen.rs]
2026-10-03 Add button and status support
2026-10-03 button rework
2026-10-03 init all buttons
2026-10-04 add last status to status screen to avoid constant redraws
    [screen.rs]
2026-10-06 Interrupt based button handling working for up, down, and select buttons.
2026-10-06 left and right buttons added
2026-10-07 remove spi module
2026-10-10 Added Features: - Highlight menu item - Move up and down in menu - Screen clipping fix - Multi-page navigation
    [buttons.rs, main.rs, screen.rs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]
2026-10-11 Implemented the UART bridge and power + ESD. Still needs some work on the transistors, but each bus should be connected now.
2026-10-19 Basic audio path working, still need to flesh out DAC logging and error handling. Mostly using symphonia sample code.

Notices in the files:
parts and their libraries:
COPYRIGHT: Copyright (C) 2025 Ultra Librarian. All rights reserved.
